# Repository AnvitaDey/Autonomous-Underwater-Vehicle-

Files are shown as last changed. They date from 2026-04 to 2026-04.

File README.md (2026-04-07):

# Autonomous Underwater Vehicle (AUV)

Developed this project as part of the **Robofest Gujarat 5.0 (GUJCOST) AUV Challenge**, focusing on designing and building a fully functional Autonomous Underwater Vehicle for real-world underwater tasks.

The system integrates mechanical design, embedded systems, and computer vision to perform operations such as navigation, inspection, and object interaction.

---

## 🚀 Overview

The AUV features:

* PVC frame for structural strength and low drag
* Six-thruster configuration enabling multi-axis control
* Raspberry Pi for high-level processing and Pixhawk (ArduSub) for stabilization
* Vision pipeline using OpenCV for perception tasks

The vehicle is capable of controlled motion in surge, sway, heave, and yaw, ensuring stable underwater navigation.

---

## ⚙️ System Design

### Mechanical System

* Rigid and modular frame design with balanced mass distribution
* 6 thruster configuration for dof 
* Waterproof electronics enclosure
* Dedicated mounts for sensors, camera, and manipulator

### Electronics & Control

* Pixhawk 2.4.8 for real time control and sensor fusion
* Raspberry Pi 4 running BlueOS and ROS2
* ESC-controlled BLDC motors for propulsion
* Sensors: camera, pressure sensor, leak detection

### Software

* ROS2 + MAVROS architecture
* MAVLink communication
* OpenCV-based perception
* QGroundControl for monitoring and mission execution
* 
---

## Contributions

* Designed key mechanical components and assemblies using **Fusion 360**
* Worked on structural layout, stability, and component integration
* Developed mounts and enclosure systems for underwater operation
* Contributed to vision pipeline with **HSV-based color segmentation using OpenCV**

---

## 🏆 Achievements

* Advanced to **Round 2** in Robofest Gujarat 5.0
* Secured **₹50,000 in project funding**
* Successfully developed and presented a working prototype

---

## 📂 Repository Structure

* `mechanical-design/` → CAD models and components
* `system-design/` → full AUV assemblies and iterations
* `gripper/` → manipulator design
* `system architecture/` → circuit diagram 

---

## 📄 Technical Documentation

For a detailed breakdown of system design, hardware architecture, and implementation:

[View Full Technical Report](./Technical_Document_Final.pdf)

## 🛠️ Tools & Technologies









---

## 📸 Preview

AUVbody_ideation

---

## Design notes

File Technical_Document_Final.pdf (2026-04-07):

Gujarat Council on Science & Technology Dept. of Science & Technology, Govt. of Gujarat

Technical Report for
Level-2 Proof of Concept (PoC) Stage for
ROBOFEST-GUJARAT 5.0 Competition Level: Senior
Category: Autonomous Underwater Vehicle
Application No.: R520251182
Name of Mentor: Pramod Sreedharan
Name of Institute: Amrita Viswa Vidyapeetham, Amritapuri Campus Mobile No.: 9347682107
E-mail Id: : raviganesh812@gmail.com

### 1. Perspective View of the Robot

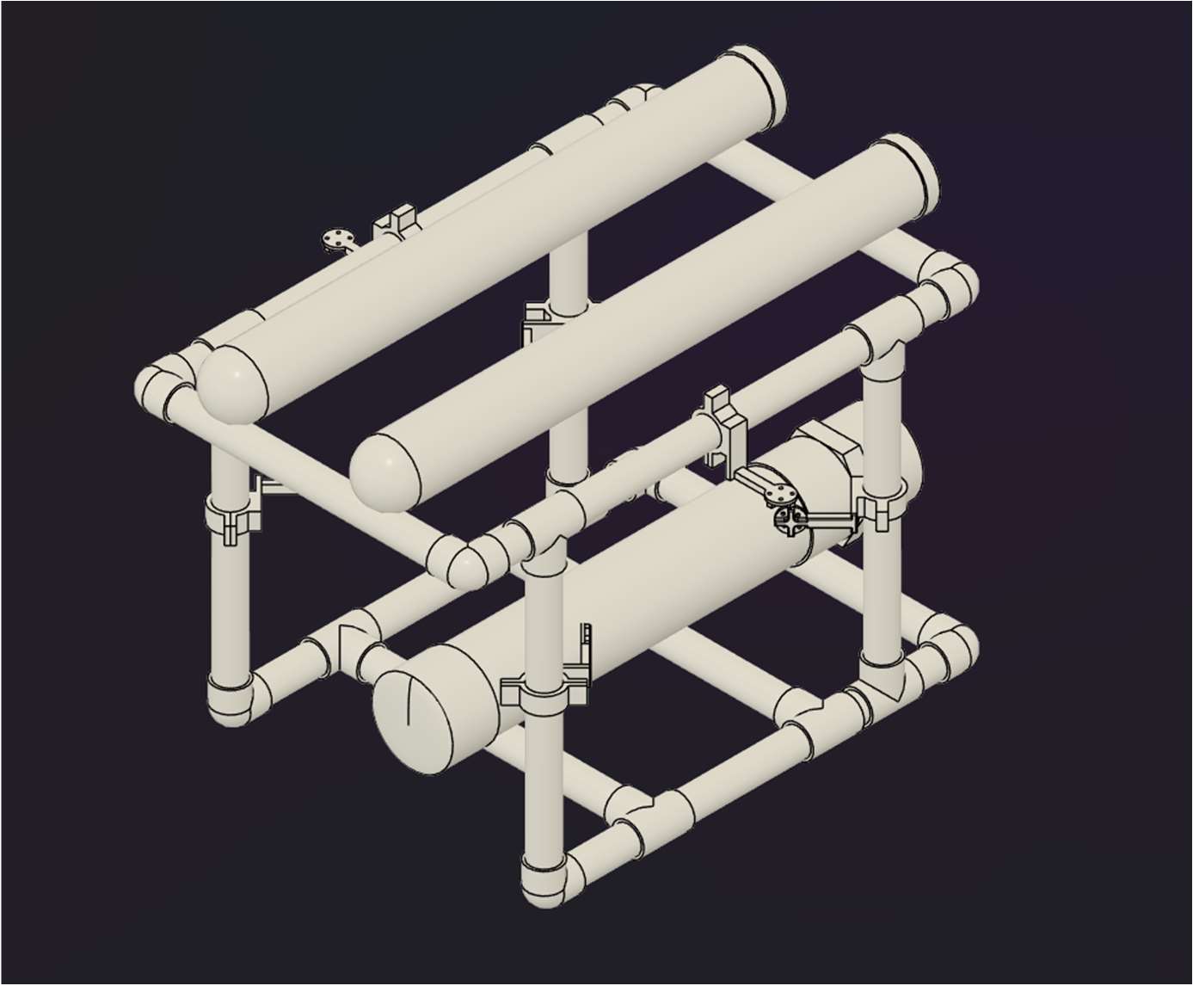
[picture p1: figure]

- Description:
The proposed robot is an Autonomous Underwater Vehicle (AUV) designed for underwater exploration and intervention tasks. It features a hydrostatically stable PVC hull with an acrylic front dome for optical clarity. The vehicle is equipped with six underwater thrusters arranged in a vectored configuration for full motion control in surge, sway, heave, and yaw. Core intelligence is managed by
a Raspberry Pi 5 running ROS 2 Humble, handling sensor fusion, mission planning, and manipulator control. A Pixhawk 2.4.8 flight controller provides low-level thruster control and stabilization. The system integrates multiple sensors including stereo cameras, depth sensors, hydrophones, and leak detectors for comprehensive environmental perception and task execution
a. Design Outlay and Description:

o The Autonomous Underwater Vehicle (AUV) is designed as a compact and modular robotic system capable of stable underwater navigation, depth control, and visual inspection. The overall design integrates a rigid mechanical frame, a six-thruster propulsion configuration, and a balanced mass distribution to ensure stability and maneuverability in a submerged environment. The thrusters are symmetrically arranged using a combination of clockwise and counter-clockwise motors, enabling full control over all degrees of freedom and minimizing unwanted torque effects. The mechanical layout also accommodates a sealed electronics enclosure, battery placement for a low center of gravity, and front-mounted sensors and manipulator for operational tasks.
o The control architecture of the AUV follows a layered design approach, where low-level control and stabilization are handled by a Pixhawk flight controller running ArduSub firmware, while high-level processing and communication are managed by a Raspberry Pi running BlueOS. Sensor inputs such as depth and orientation are continuously processed to generate real-time control outputs for precise motion control. Communication with the ground control station is achieved through Ethernet using QGroundControl, enabling monitoring, configuration, and mission execution. This integrated design ensures reliable operation, scalability, and suitability for both manual and autonomous underwater missions.
b. Description of Hardware:
This section describes the complete hardware architecture of the Autonomous Underwater Vehicle (AUV). The system is designed to provide stable underwater propulsion, precise control, sensing, and onboard computation using commercially available components.
b1. Mechanical System
The AUV is designed with a rigid frame structure with PVC pipes that supports propulsion units, electronics enclosure, battery mounting, and a front-facing manipulator. The frame ensures structural integrity while minimizing hydrodynamic drag during underwater operation.
Frame and Layout
- The propulsion motors are symmetrically mounted around the vehicle’s center of mass to ensure balanced thrust and maneuverability.
- Electronics such as the Pixhawk, Raspberry Pi, power distribution board, and power module are housed inside a sealed waterproof enclosure.
- Batteries are mounted low in the frame to improve stability and maintain a low center of gravity.
- A front-mounted camera provides visual feedback for navigation and manipulation tasks.
- A servo-actuated manipulator is attached at the front of the vehicle for object interaction. b2. Drive System & Controller
Propulsion Motors
The AUV uses a total of six Brushless DC (BLDC) motors for underwater propulsion:
- 3 × CW BLDC Motors (920 KV)
- 3 × CCW BLDC Motors (920 KV)
These motors are arranged in pairs to counteract torque effects and improve directional stability. The use of both clockwise (CW) and counter-clockwise (CCW) motors eliminates unwanted rotational moments during operation.
Key Features: - High efficiency and reliability - Suitable for continuous operation - Capable of providing sufficient thrust for underwater maneuvering.
Electronic Speed Controllers (ESCs)
- 6 × 30A ESCs are used to control the speed and direction of the BLDC motors.
- Each ESC receives PWM control signals from the Pixhawk autopilot.
- ESCs are powered directly from the battery through the power distribution board. Functions of ESCs: - Converts DC battery power into three-phase AC for BLDC motors -Enables precise motor speed control - Supports rapid response to control commands

Flight Controller / Autopilot
- Pixhawk 2.4.8 is used as the primary control unit.
- Runs ArduSub firmware, specifically designed for underwater vehicles.
- Handles real-time control tasks such as:
o Stabilization
o Thruster mixing
o Sensor fusion
o Navigation and depth control
Companion Computer
- Raspberry Pi 4 Model B acts as the companion computer.
- Runs BlueOS, which manages:
o MAVLink communication
o Video streaming
o Network connectivity
o High-level control and extensions
The Raspberry Pi communicates with the Pixhawk via USB/UART using the MAVLink protocol.
Manipulator Control
- A servo motor is used to actuate the manipulator mechanism.
- Controlled directly by the Pixhawk through a PWM output.
- Enables grasping or interaction with underwater objects.
b3. Electronics & Instrumentation: Power System
a) Battery
- 2 × 14.8V (4S) 5200 mAh LiPo batteries are used.
- High discharge rating (40C–80C) ensures sufficient current for motors and electronics.
b) Power Distribution Board (PDB)
- Distributes battery power to:
o ESCs
o Power module
- Ensures organized and safe power routing.
c) Power Module
- Steps down battery voltage and supplies regulated power to the Pixhawk.
- Provides voltage and current sensing for real-time monitoring.
d) Computing and Control Electronics
Component | Function
Raspberry Pi 4 | Companion computer, BlueOS, video processing
Pixhawk 2.4.8 | Autopilot, motor control, sensor fusion
ESCs | Motor control
PDB | Power distribution

Sensors
a) Camera
- Raspberry Pi camera module is used for real-time underwater vision.
- Mounted at the front of the vehicle.
- Used for navigation, inspection, and object detection.
b) Pressure Sensor
- MS5837-02BA waterproof pressure sensor is used.
- Provides accurate depth measurement.
- Communicates with the Pixhawk via I2C.
- Functions: - Depth estimation - Altitude hold - Safety monitoring b4. Working Level Software

Raspberry Pi – mission computer

- OS: BlueOS
- Framework: ROS2 – MAVRos, using python and C
- Communication protocols: MAVLink
- Vision system: OpenCV
- Qground control, Mission planner

Pixhawk 2.4.8 - Flight Controller

- Firmware – ArduSub
1. Complete and exhaustive listing of all the hardware / component / equipment (electronics and mechanical)
A. Controller of the Robot:

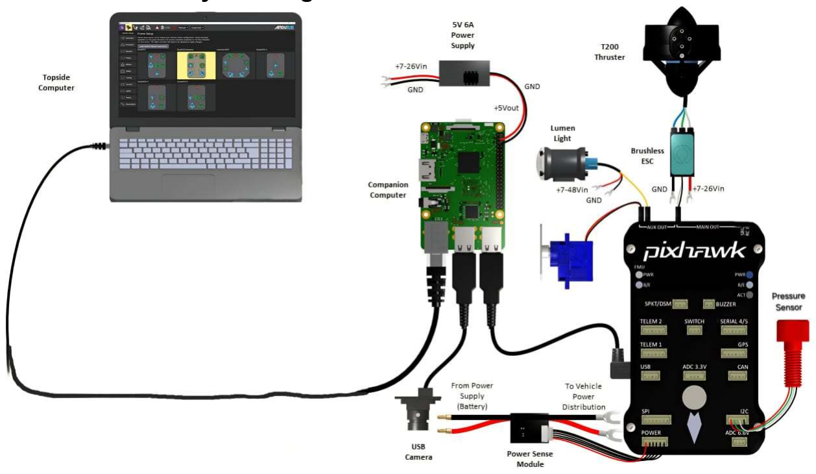
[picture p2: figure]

Electrical assembly & wiring

Power Connections

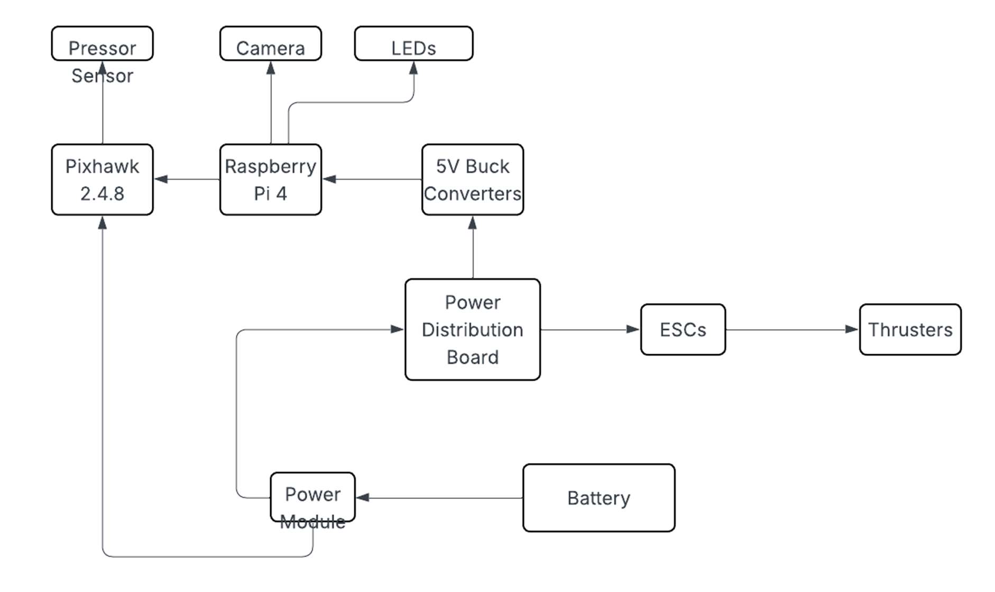
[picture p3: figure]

List Of Components:

Sln. | Component | Model / Specification | Quantity | Description
1 | Brushless DC Motor (CCW) | Pro Range DX2312, 960 KV (CCW) | 3 Provides thrust for | propulsion and maneuvering in counter-clockwise direction; used for balanced thrust in AUV
2 | Brushless DC Motor (CW) | Pro Range DX2312, 960 KV (CW) | 3 Clockwise rotating | motors paired with CCW motors to eliminate torque imbalance
3 Electronic Speed Controller | (ESC) | Simplifly ESC, 30A | 6 | Controls speed and direction of BLDC motors based on PWM signals from Pixhawk
4 | Servo Motor | Standard RC Servo Motor | 1 Used for | manipulator actuation to grip or interact with underwater objects
5 | Lithium Polymer Battery | GenX Power 11.1V (3S), 5200mAh, 40C | 2 Primary power | source supplying high current for motors and onboard electronics

6 | Power Module | Pixhawk Power Module (Voltage & Current Sensor) | 1 Regulates power to | Pixhawk and monitors battery voltage/current
7 | Power Distribution Board (PDB) | Drone Power Distribution Board | 1 Distributes battery | power evenly to all ESCs and onboard electronics
8 | Flight Controller | Pixhawk 2.4.8 | 1 | Main autopilot unit responsible for stabilization, navigation, and control
9 | Companion Computer | Raspberry Pi 4 Model B - 8gb ram | 1 Runs BlueOS, | handles vision processing, networking, and high-level control
10 | Camera Module | Raspberry Pi Camera Module | 1 Provides live video | feed for navigation, monitoring, and inspection
11 | Pressure Sensor | MS5837-2BA Waterproof Pressure Sensor | 1 Measures water | pressure to calculate depth of the AUV
12 | Ethernet Cable | CAT6 Ethernet Cable | 1 | Used for communication between Raspberry Pi and surface control station
B. Mechanical Components
a. Mechanical Modules
The AUV features a rigid, lightweight frame designed to support propulsion units, electronics, batteries, sensors, and a manipulator. Six thrusters are symmetrically mounted to enable full 6-degree-of-freedom motion. Dedicated mounts are provided for the Pixhawk, Raspberry Pi, camera, and pressure sensor, ensuring stability and easy maintenance.
b. Fabrication Components
The frame and mounts are fabricated using aluminum, PVC, and 3D-printed components for strength and corrosion resistance. Waterproof enclosures protect electronic components, while stainless-steel fasteners and brackets ensure secure assembly in underwater conditions.
c. Tools and Equipment Used
Basic fabrication tools such as drills, screwdrivers, soldering iron, multimeter, and 3D printer are used for assembly, wiring, and waterproof sealing.
C. Motor System Used & Assembly

The AUV uses six D2212 920KV BLDC motors (three CW and three CCW) controlled by 30A ESCs. This balanced configuration minimizes torque effects and improves stability. Motors are securely mounted to the frame, with ESCs connected to a power distribution board and controlled via PWM signals from the Pixhawk, enabling precise thrust and manoeuvring control.

### 2. Complete and exhaustive listing of all the software used in Robo-making

A.Software Used

A1. BlueOS
Why BlueOS for an AUV
- Advantages over standard Raspberry Pi OS
- Pre-configured MAVLink routing
- Built-in ArduSub support
- Web-based UI (no monitor needed)
- Integrated video streaming
- Designed specifically for ROV/AUV use Hardware Requirements
- Mandatory
- Raspberry Pi 4 Model B (8GB)
- Pixhawk (Pixhawk 2.4.8)
- SD card
- Ethernet cable
- Stable 5V 3A power supply for Pi
- Additional
- USB camera / CSI camera
- Depth sensor (I2C)
- Leak sensor
Companion sensors
- Power System Design
Battery (3S / 4S Li-ion or LiPo)
|→ Buck Converter (5V 3–5A)
| | → Raspberry Pi 4
|→ Power Module
| → Pixhawk
Flashing ArduSub
BlueOS → Autopilot Firmware - Select ArduSub - Select Pixhawk model – Flash firmware Pixhawk Connection
- Pixhawk USB → Pi USB
MAVLink in BlueOS
- MAVLink Flow
Pixhawk ⇄ BlueOS ⇄ Laptop (QGC)

A2. QGroundControl:

QGroundControl (QGC) is the primary Ground Control Station (GCS) software used for monitoring, controlling, and configuring the Autonomous Underwater Vehicle (AUV). In this system, QGroundControl interfaces with the Pixhawk autopilot running ArduSub firmware through the Raspberry Pi companion computer running BlueOS. It provides a unified graphical interface for vehicle setup, real-time telemetry visualization, mission planning, and manual control.

Role of QGroundControl in the AUV System

In the proposed AUV architecture, QGroundControl functions as the operator-facing control and monitoring platform. It does not directly control motors or sensors but communicates with the Pixhawk via MAVLink messages routed through BlueOS. QGC enables the operator to supervise vehicle behavior, issue commands, and visualize system health in real time.

Connection and Initialization Process
1. The Raspberry Pi and Pixhawk are powered ON.
2. BlueOS boots and establishes MAVLink communication with the Pixhawk.
3. The laptop is connected to the Raspberry Pi using an Ethernet cable.
4. QGroundControl is launched on the laptop.
5. QGC automatically connects to the AUV and displays vehicle status.
No manual port configuration is required, as BlueOS manages MAVLink routing.

The communication chain is established as follows:
QGroundControl (Laptop)
⇅ MAVLink (UDP)
Raspberry Pi 4 (BlueOS)
⇅ MAVLink (USB/UART)
Pixhawk 2.4.8 (ArduSub)

Operational Control Modes
QGroundControl allows the operator to select and monitor different control modes supported by ArduSub:
- Manual Mode: Direct operator control of thrusters
- Stabilized Mode: Automatic attitude stabilization
- Depth Hold Mode: Maintains constant depth using pressure sensor feedback
- Autonomous / Assisted Modes: Executes predefined behaviors or missions Mode changes are transmitted as MAVLink commands.

Real-Time Monitoring and Telemetry
QGroundControl displays real-time telemetry data, including:
- Vehicle attitude (roll, pitch, yaw)
- Depth and vertical velocity
- Battery voltage and current
- Thruster output levels
- Sensor health and system status
Graphical indicators and warnings assist the operator in maintaining safe operation.

Mission Planning and Control
For semi-autonomous operation, QGroundControl enables:
- Creation of waypoint-based missions
- Depth and speed constraints

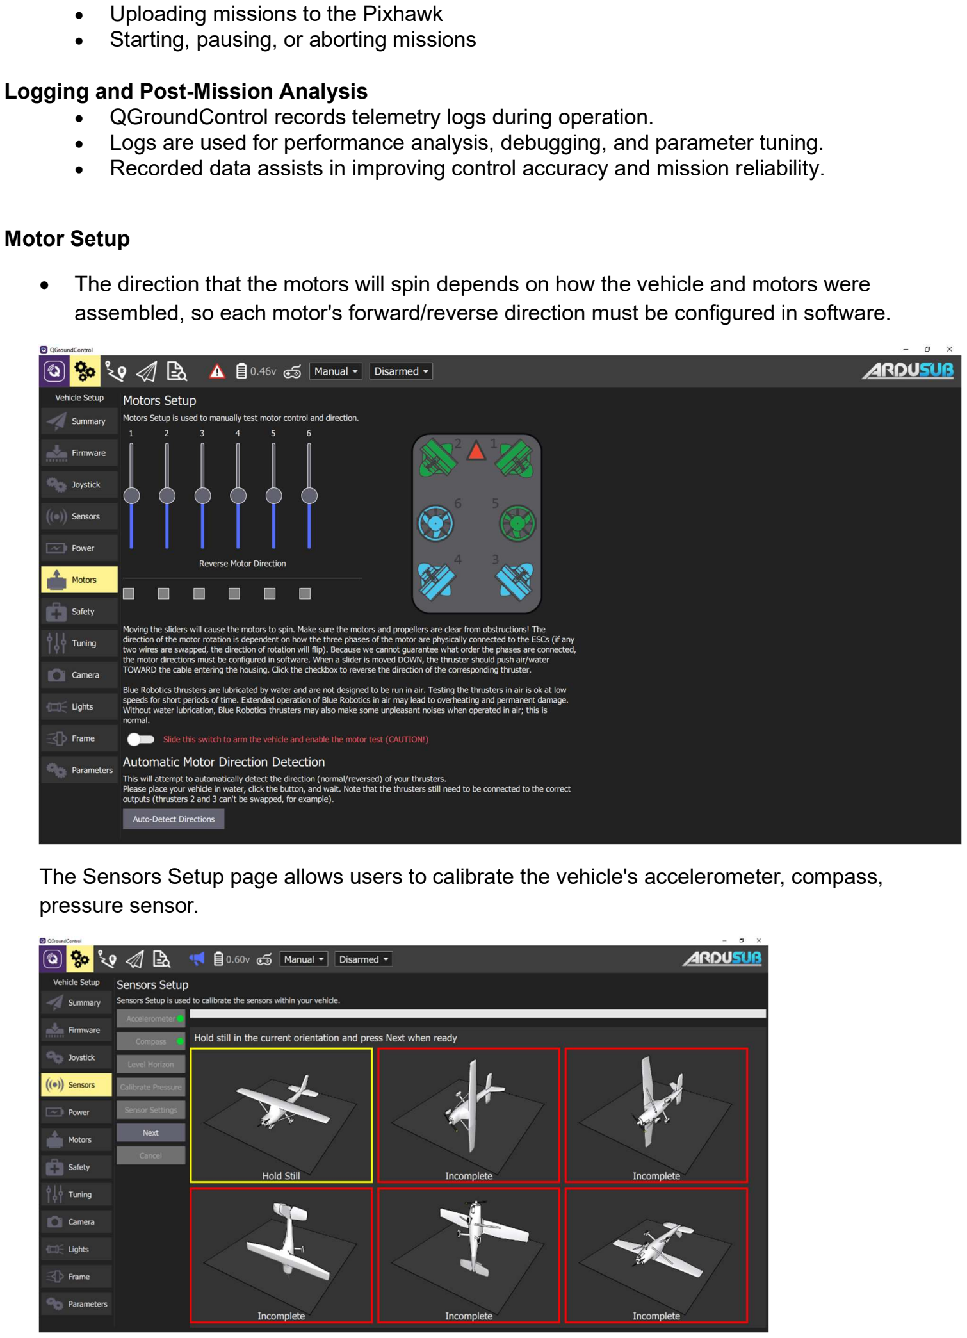
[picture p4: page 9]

- Uploading missions to the Pixhawk
- Starting, pausing, or aborting missions

Logging and Post-Mission Analysis
- QGroundControl records telemetry logs during operation.
- Logs are used for performance analysis, debugging, and parameter tuning.
- Recorded data assists in improving control accuracy and mission reliability.

Motor Setup

- The direction that the motors will spin depends on how the vehicle and motors were assembled, so each motor's forward/reverse direction must be configured in software.

The Sensors Setup page allows users to calibrate the vehicle's accelerometer, compass, pressure sensor.

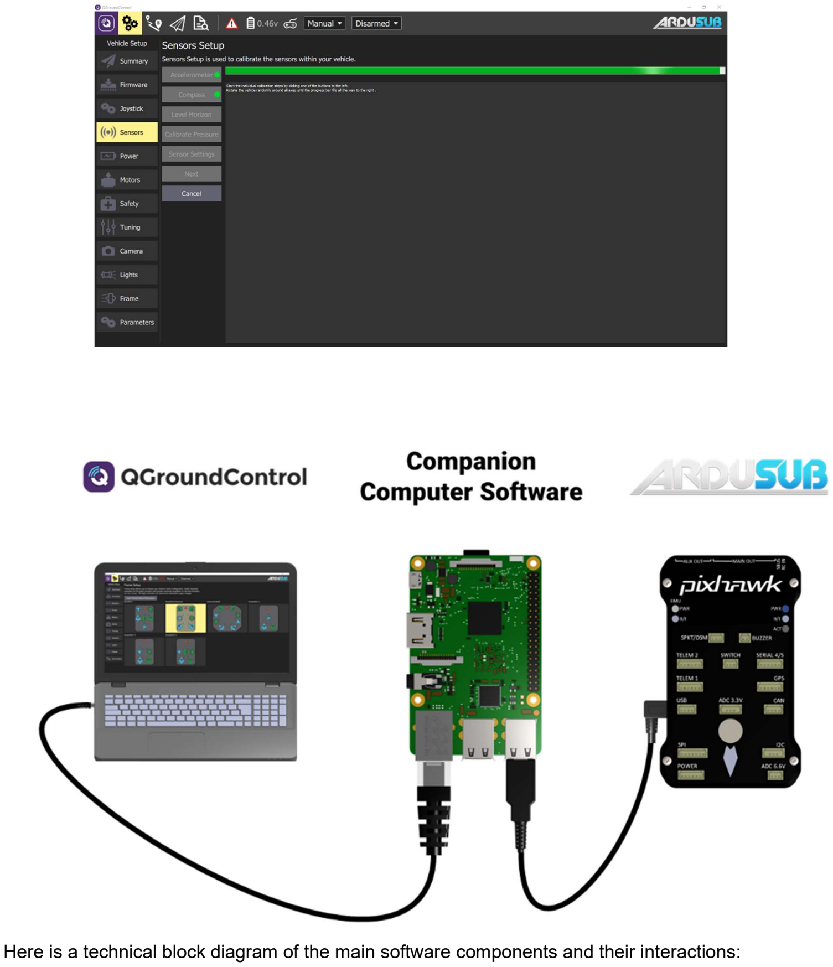
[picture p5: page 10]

Here is a technical block diagram of the main software components and their interactions:

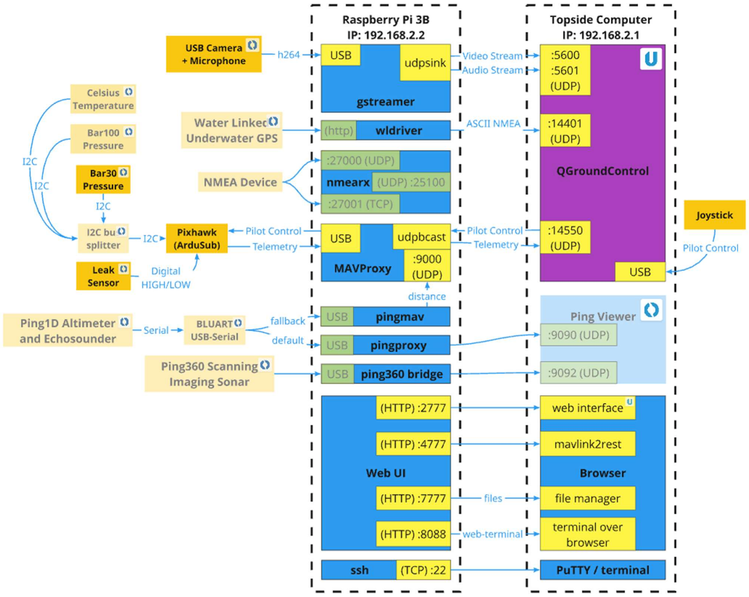
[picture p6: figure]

A3. Pymavlink
ArduSub communicates with a protocol called MAVLink. Pymavlink is a python implementation of the MAVLink protocol. With pymavlink, it is possible to create a python script to read sensor data and send commands to an ArduSub vehicle.

A4. OpenCV
OpenCV (Open Source Computer Vision) is a library to help the development of computer vision software. To perform any real-time image processing with the companion camera, we highly suggest OpenCV to do the job.

Methodology for Software

The main Flow chart of our mission is the basic outline of our whole project. Here, Vehicle Controller is our Pixhawk module which controls the thruster System and the mission computer which controls the Manipulator and receives signals from the sensors and sends signals to Manipulator and controller.

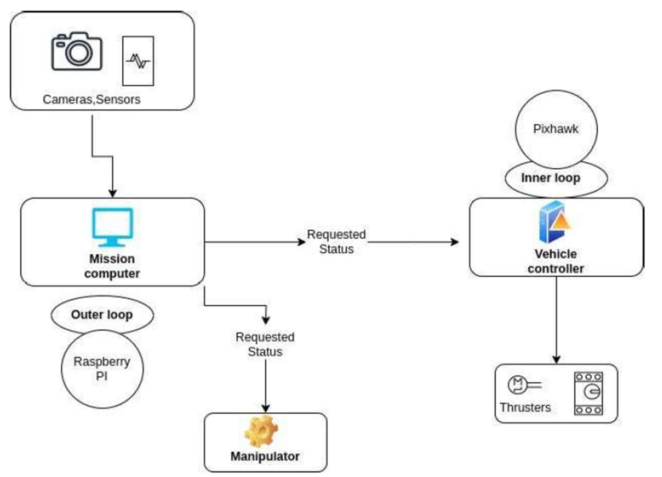
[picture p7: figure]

Now Diving deep into the Inner Loop, this is a Feed Back loop because PID control which stabilizes the system more. But there is a part which we want to focus on, there will be the noise with the data we are receiving from the Accelerometers and Gyroscopes.
Methodology of Automation
Every Autonomous robot has a process,
sensors perception decision control.
Here is the flowchart of Autonomy of our robot in which, Green nodes => Perception
Orange nodes => Decision
Light Green nodes => Control
Red nodes => Fail Safe
For each node, red boxes are the Topics that node Publishing and Blue boxes are the Topics that node subscribed for.

Here, we have two options, we can either Publisher and Subscriber relation or Server and Client relation. We opted for the Publisher and Subscriber Node because we need a continuous supply of data between the sensor and the complementary computer and controller. These continuous supply of data is called Topics. Even though, we have goal.
Now as we can see from the flow chart that our robot will get Perception like gate position, bucket position etc. from Left-hand Side nodes with the help of cameras, Sensors like Depth sensor, Leak sensor, IMU and Hydrophones, then take Decision using the mission_manager_node and Control the Actuator, Manipulator using the AUV_controller_Node, Manipulator_Controller_node also with the failsafe mechanism using the Fail-safe which can Abort the mission and ensures the Robot Safety.

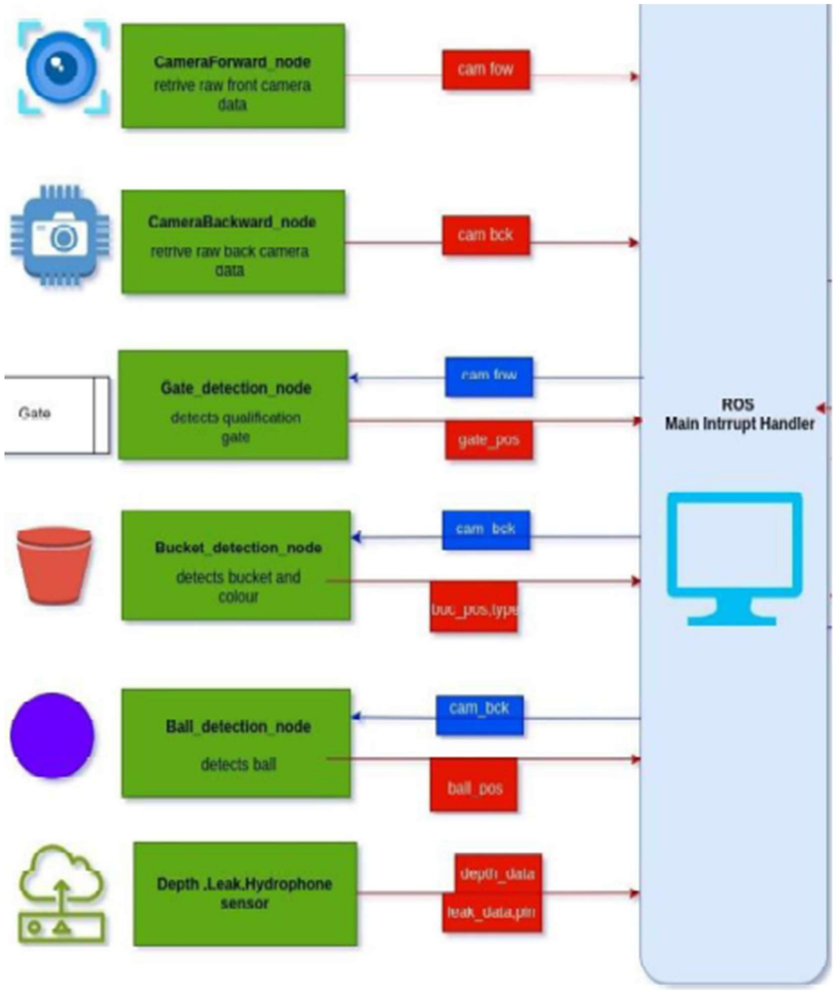
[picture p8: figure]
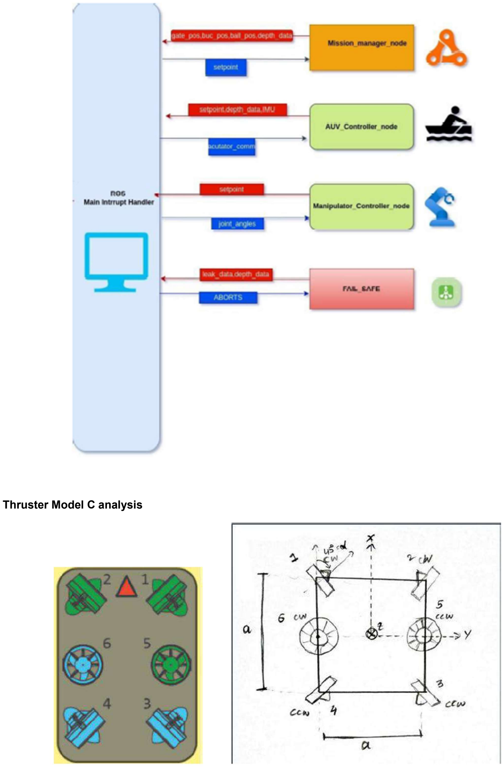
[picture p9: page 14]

Thruster Model C analysis

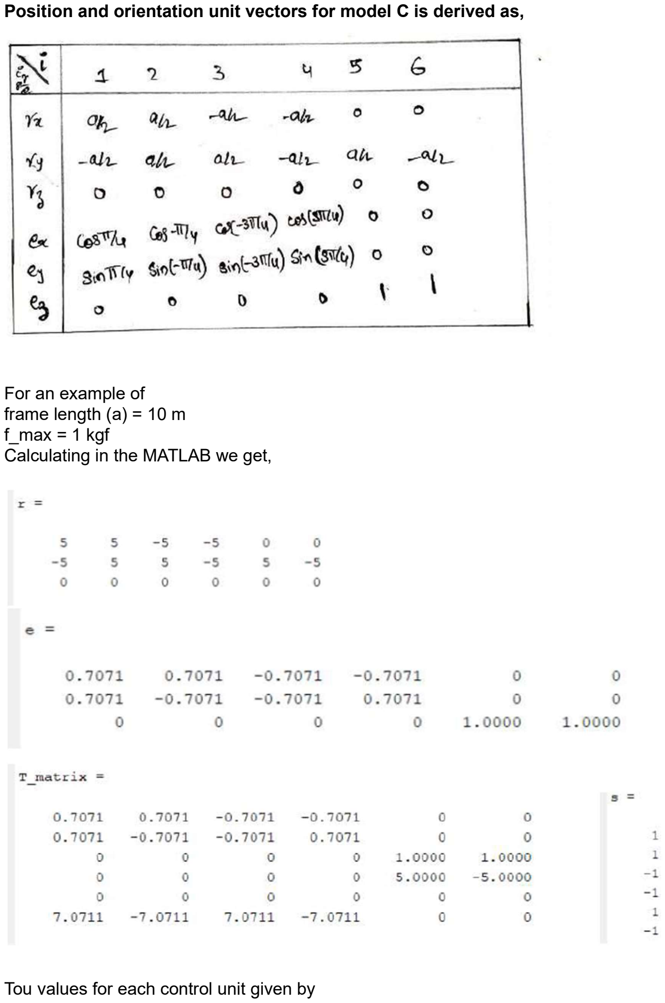
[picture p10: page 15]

Position and orientation unit vectors for model C is derived as,

For an example of
frame length (a) = 10 m
f_max = 1 kgf
Calculating in the MATLAB we get,

Tou values for each control unit given by

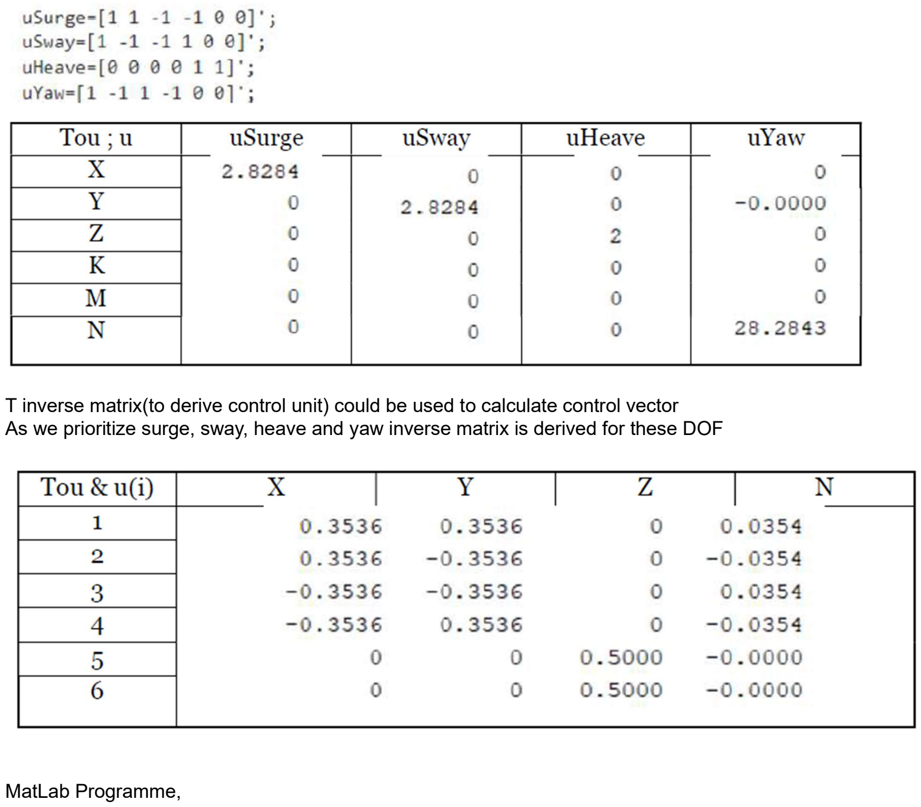
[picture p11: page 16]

T inverse matrix(to derive control unit) could be used to calculate control vector
As we prioritize surge, sway, heave and yaw inverse matrix is derived for these DOF

MatLab Programme,

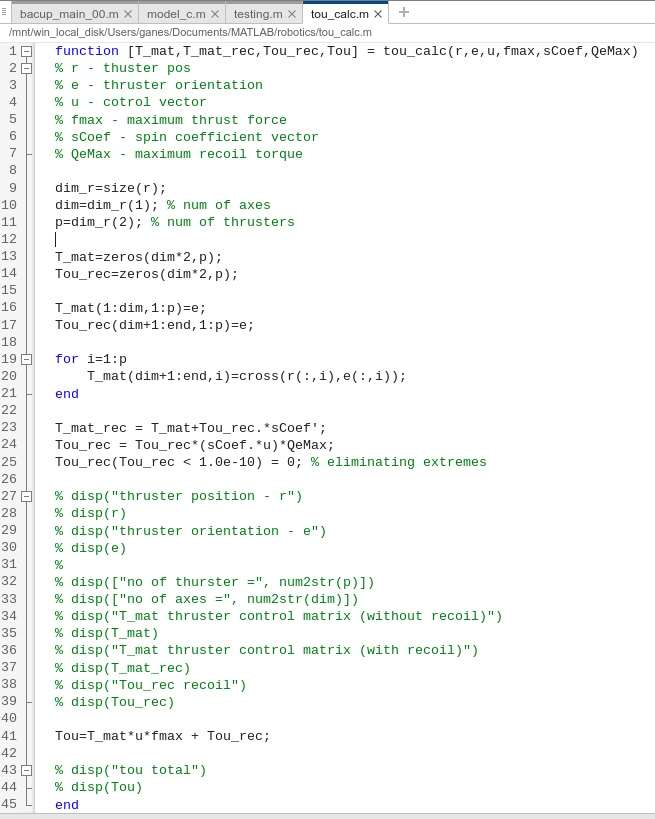
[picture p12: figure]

Propeller Design

OpenProp:
OpenProp is the ideal tool for AUV propeller design because it allows you to move beyond inefficient, off-the-shelf parts to create highly optimized, custom propulsion. By using validated naval theory, it enables you to maximize battery endurance through precise efficiency tuning, account for the unique water flow (wake) created by your AUV’s hull, and perfectly match the propeller to your motor's specific RPM. Ultimately, it provides a fast, cost-free way to go from mathematical optimization to a 3D-printable model, ensuring your vehicle achieves the longest possible mission range.

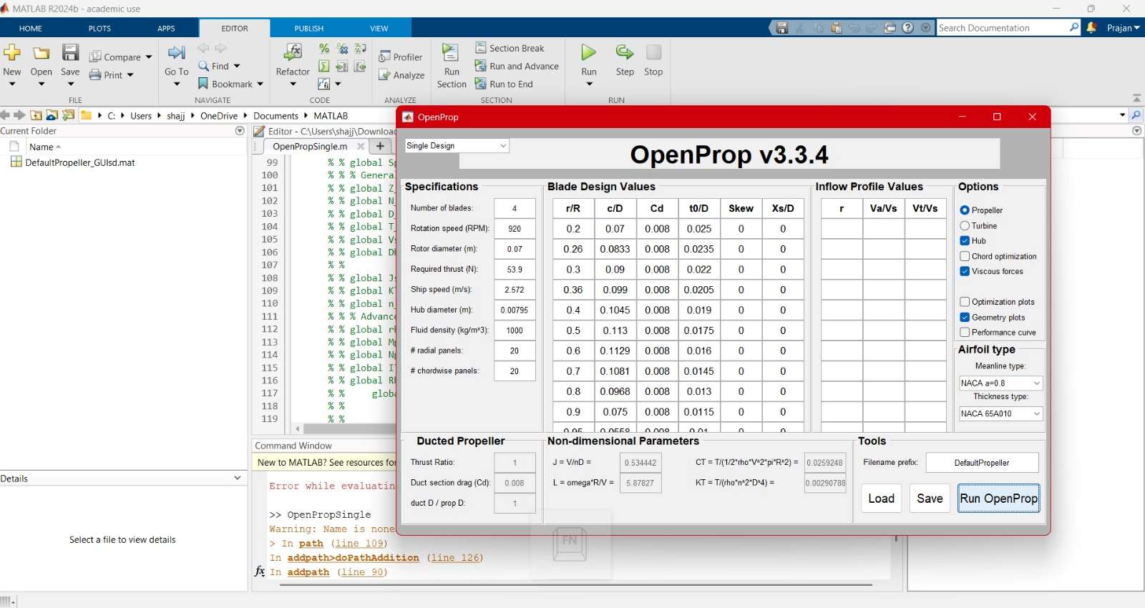
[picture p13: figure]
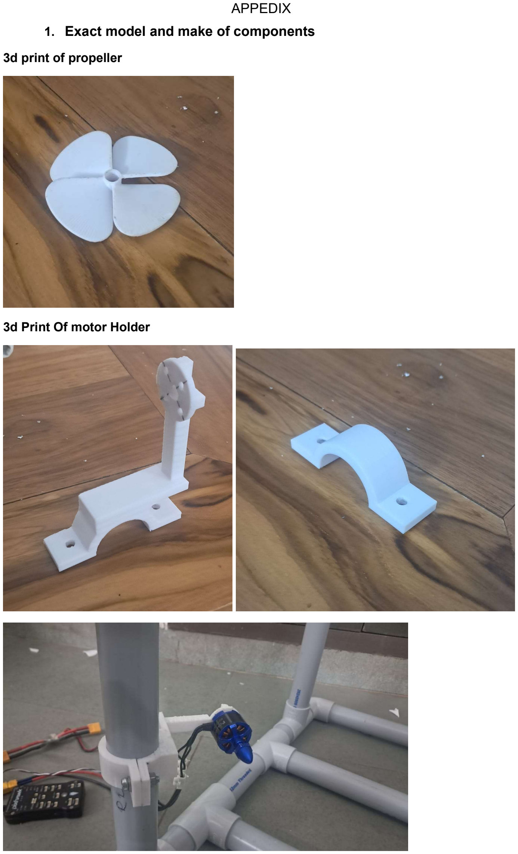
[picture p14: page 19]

APPEDIX

### 1. Exact model and make of components

3d print of propeller

3d Print Of motor Holder

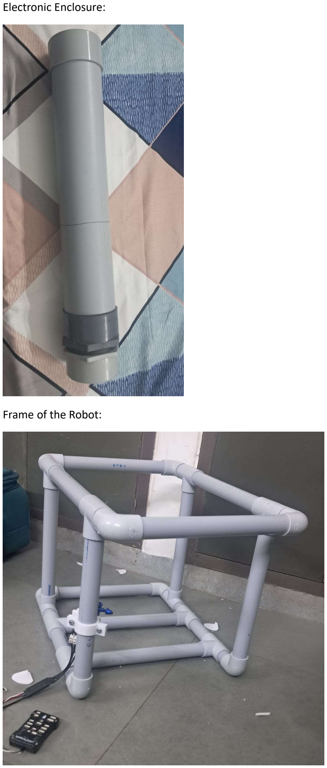
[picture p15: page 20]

Electronic Enclosure:

Frame of the Robot:

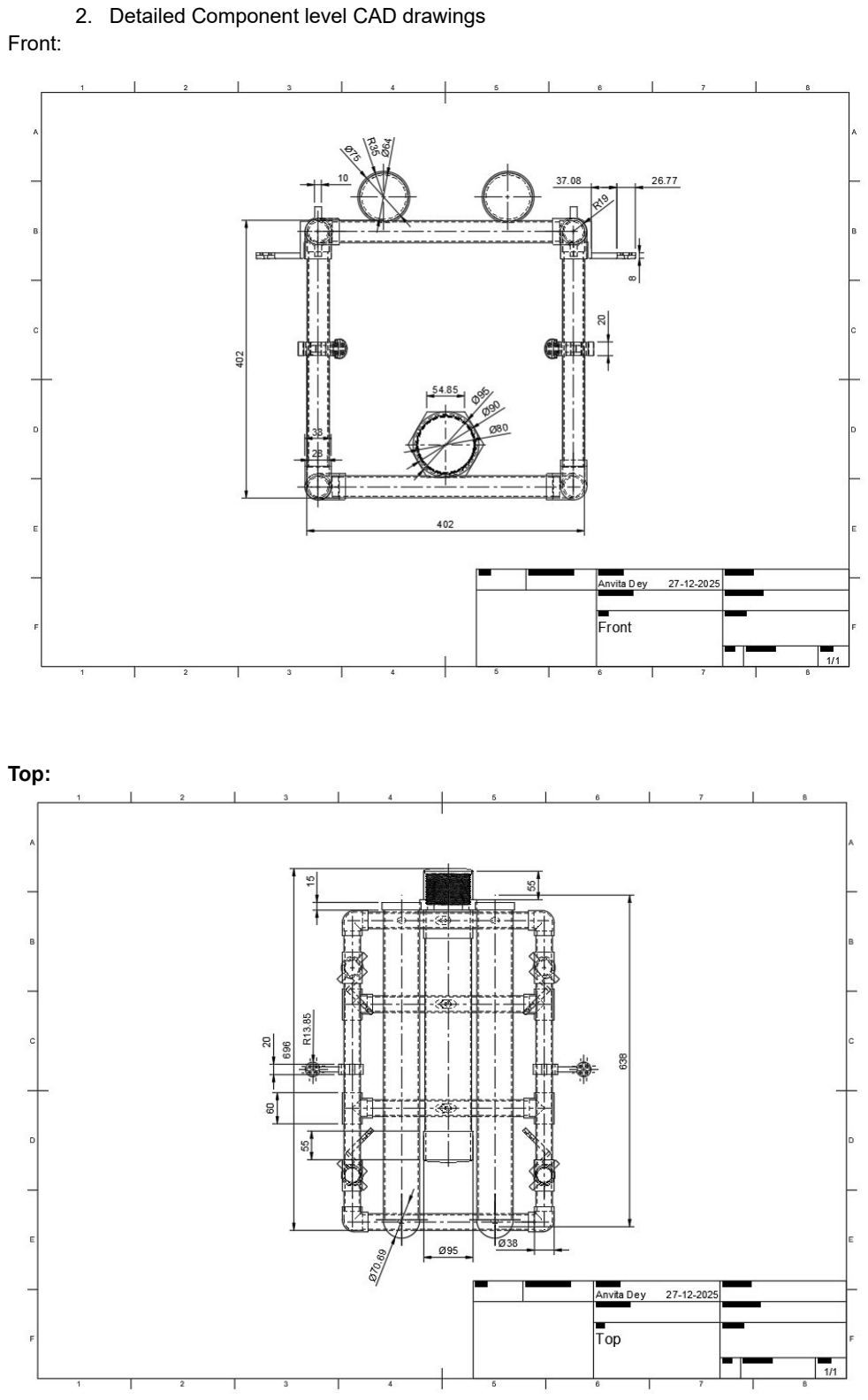
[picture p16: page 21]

### 2. Detailed Component level CAD drawings

Front:

Top:

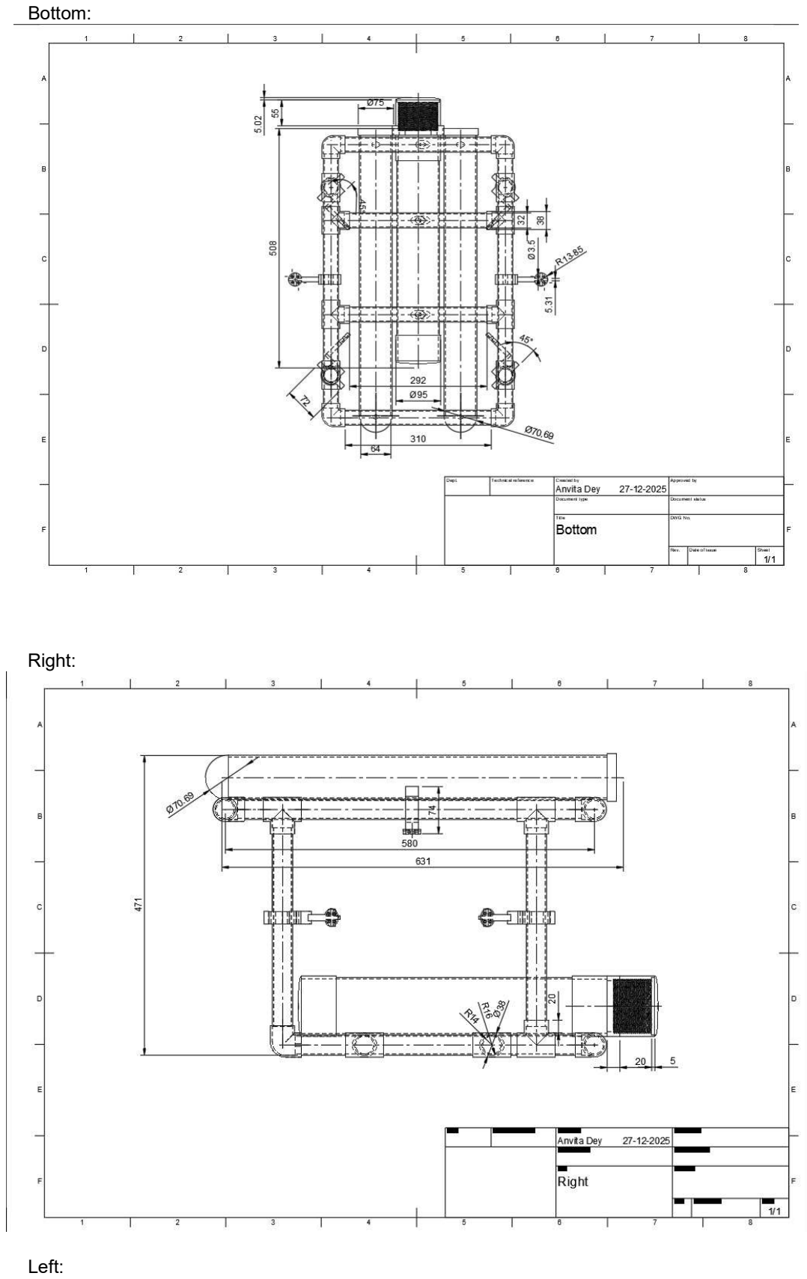
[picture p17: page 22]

Bottom:

Right:

Left:

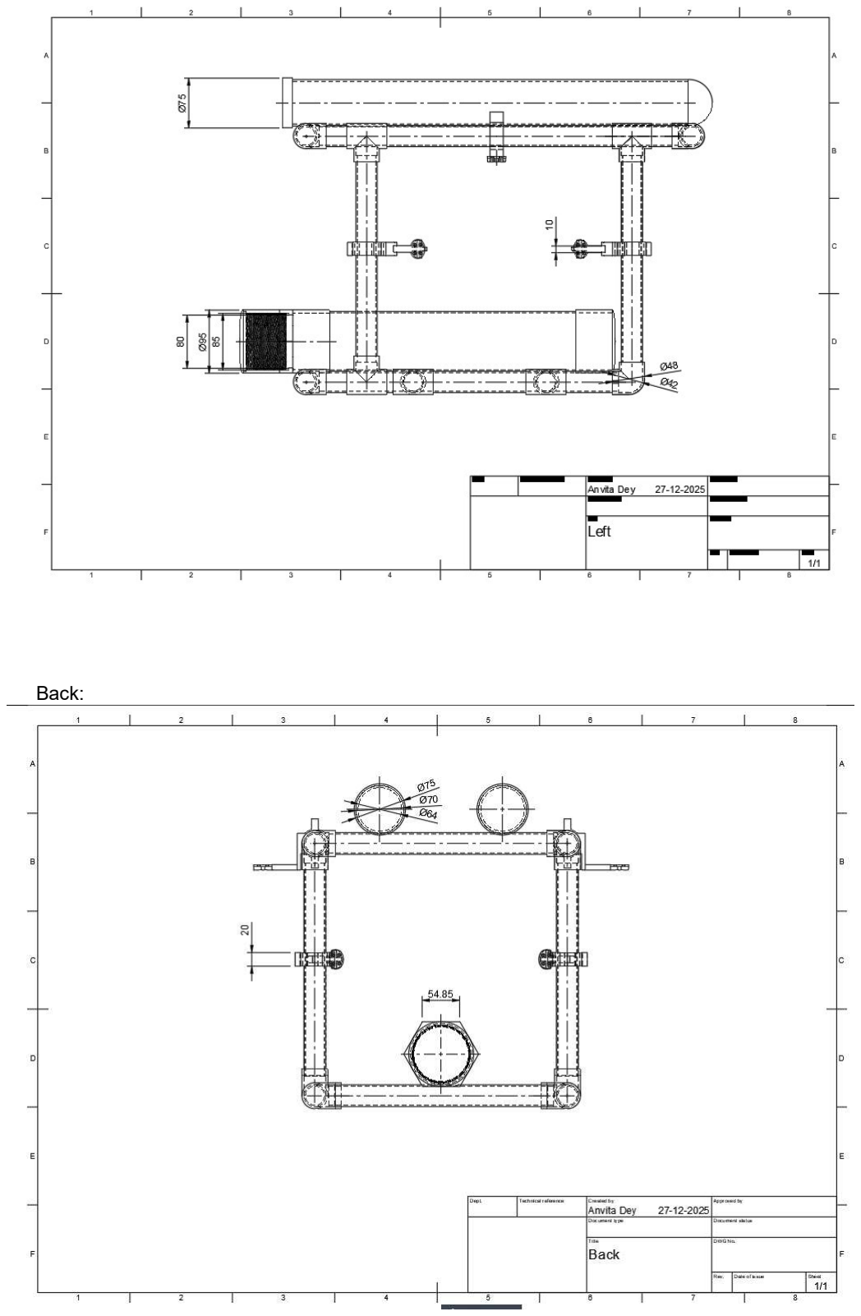
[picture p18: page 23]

Back:

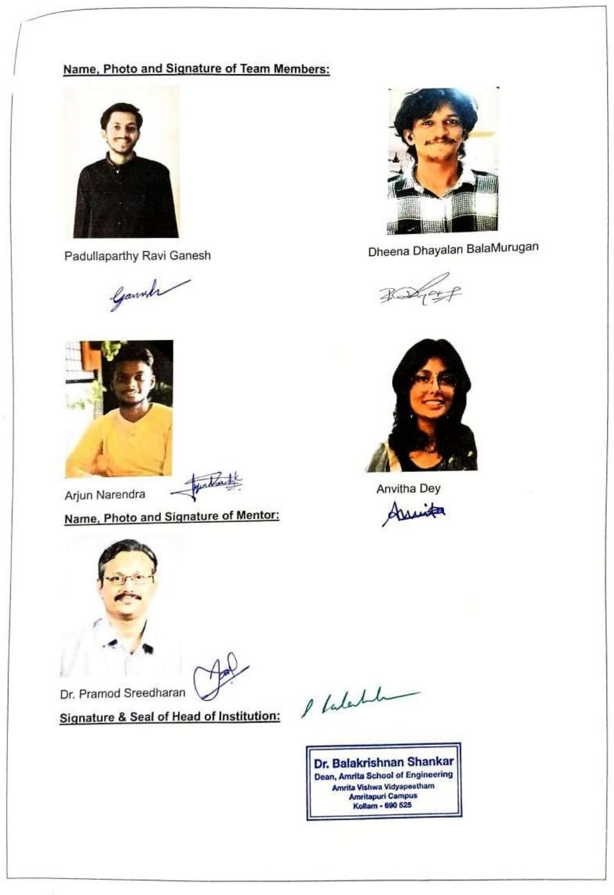
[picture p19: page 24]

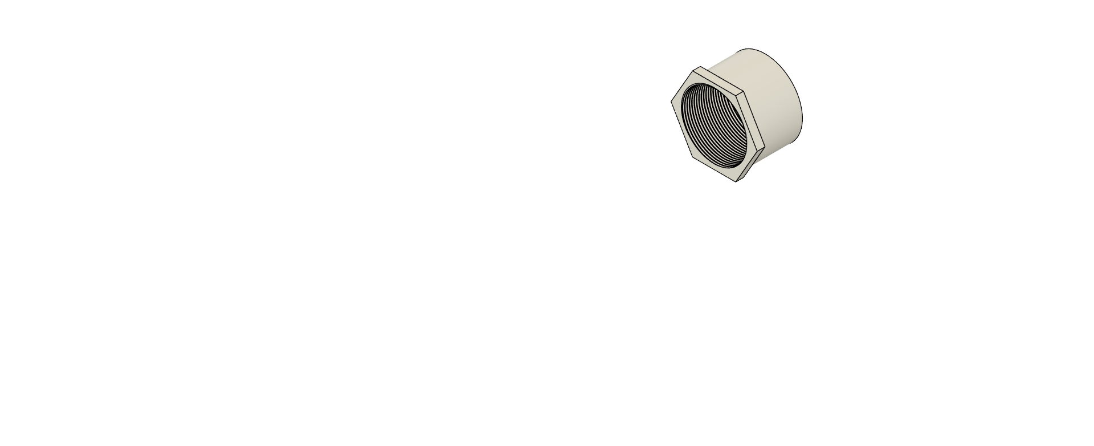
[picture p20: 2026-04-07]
mechanical-design/electronics pipe/elctronics pipe threaded cap .png

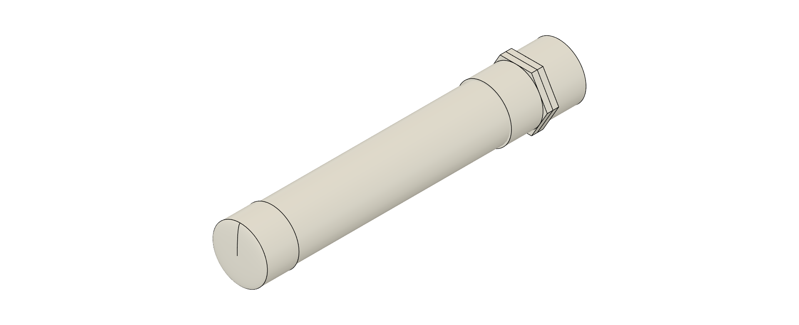
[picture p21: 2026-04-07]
mechanical-design/electronics pipe/elctronics pipe.png

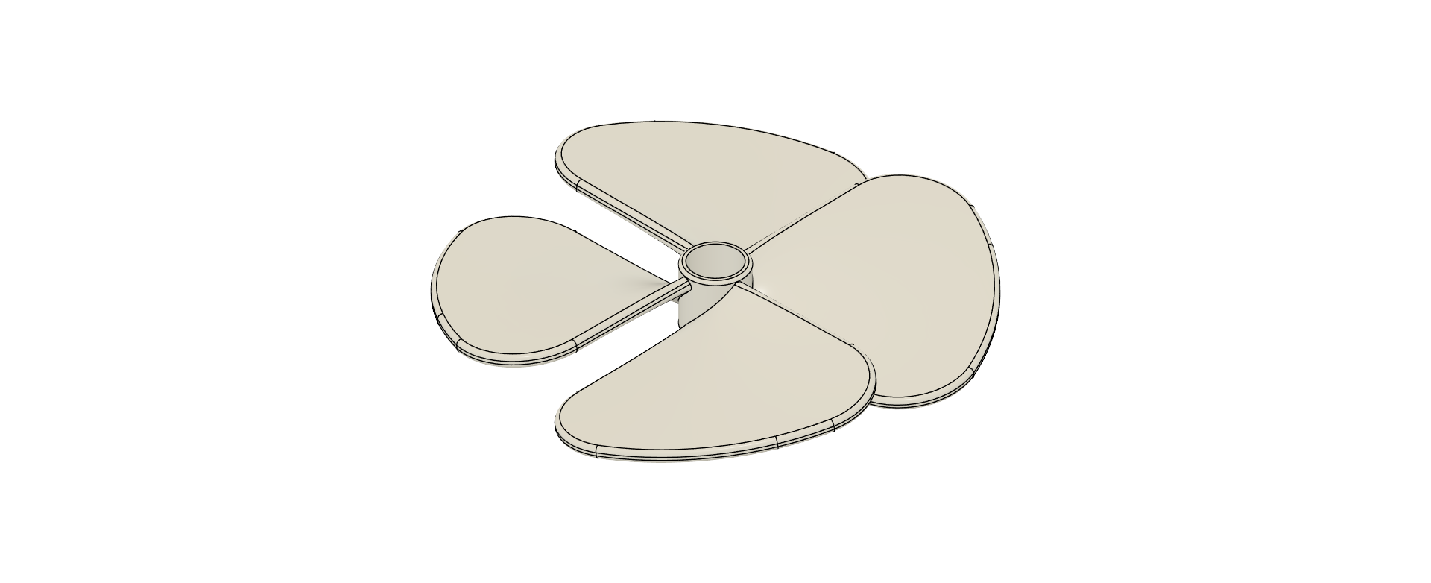
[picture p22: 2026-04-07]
mechanical-design/propeller/Propeller render.png

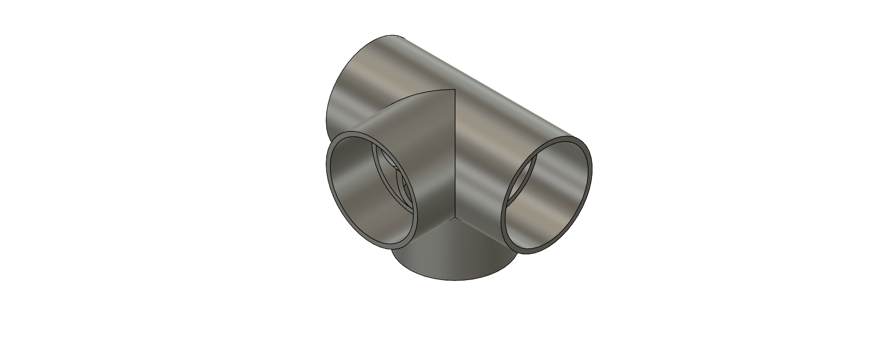
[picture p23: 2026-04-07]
mechanical-design/pvc connectors/4wayteejoint .png

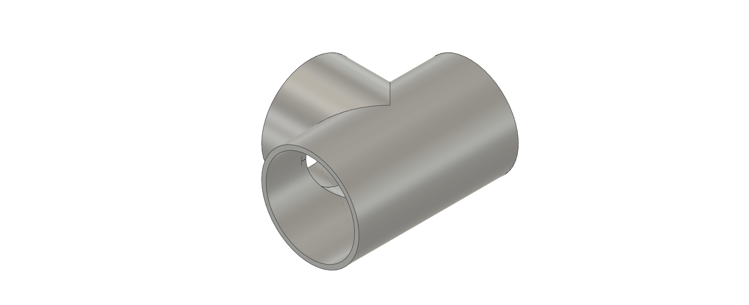
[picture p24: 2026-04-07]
mechanical-design/pvc connectors/Tjoint.png

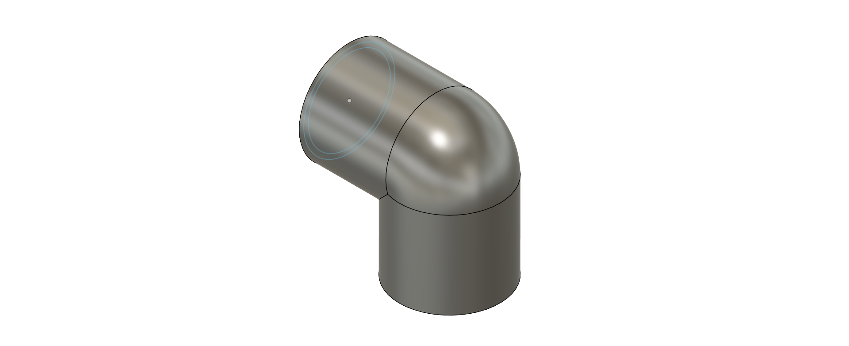
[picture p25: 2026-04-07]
mechanical-design/pvc connectors/elbow.png

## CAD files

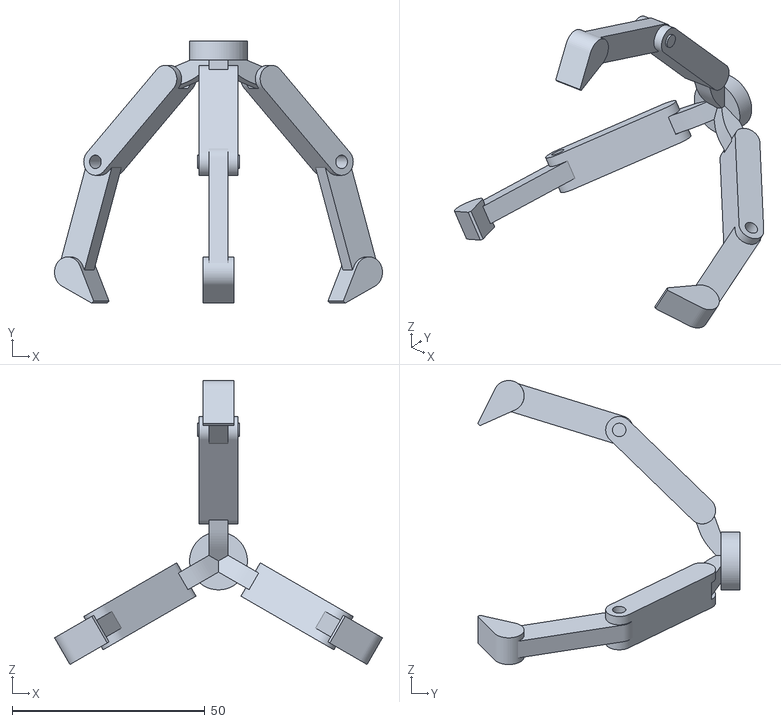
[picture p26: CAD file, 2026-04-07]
gripper/2dof_claw_.stl
85.1 x 68.1 x 73.7

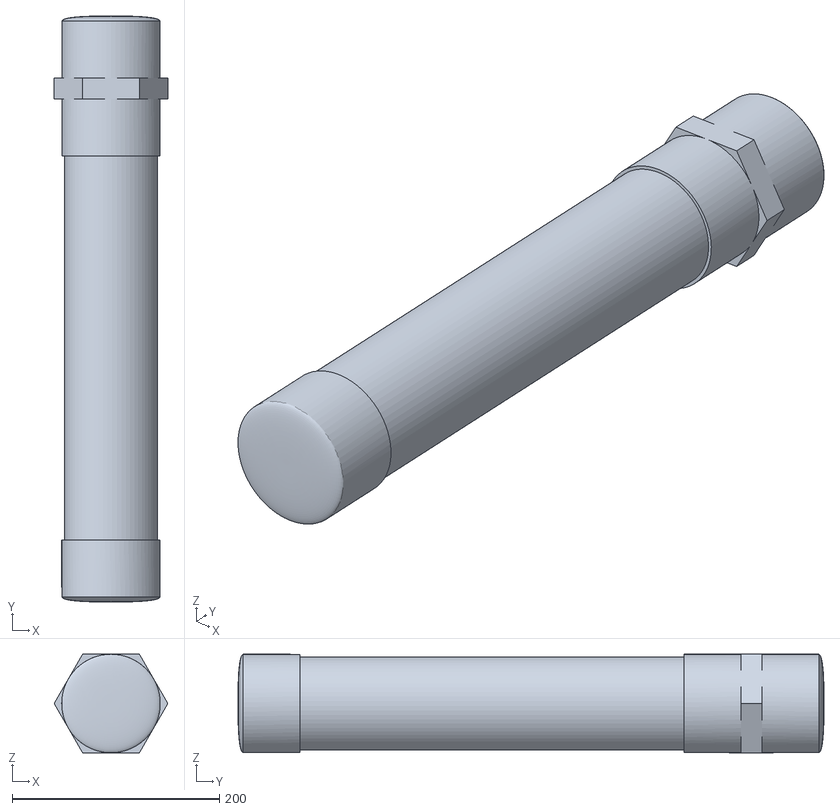
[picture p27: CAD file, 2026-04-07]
mechanical-design/electronics pipe/elctronics pipe.stl
109.7 x 565.0 x 95.0

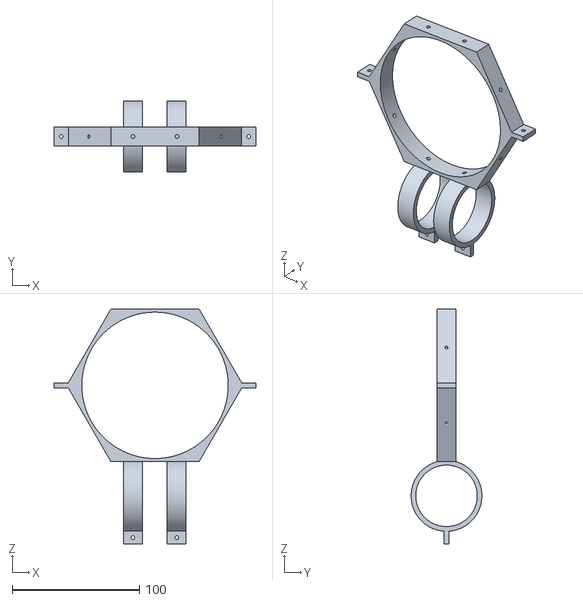
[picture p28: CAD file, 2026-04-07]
mechanical-design/hexa-holder/hexa-holder.stl
158.6 x 55.7 x 184.7

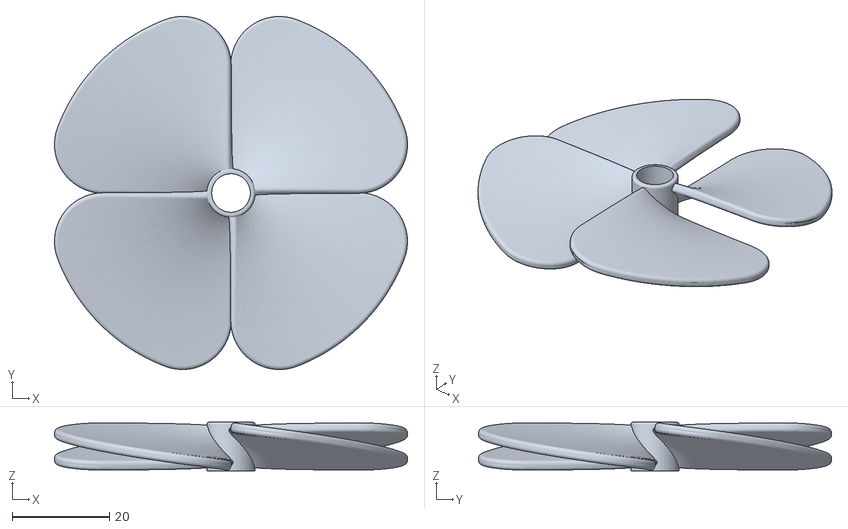
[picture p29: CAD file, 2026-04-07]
mechanical-design/propeller/Propeller_anti-clk.stl
72.5 x 72.5 x 10.0

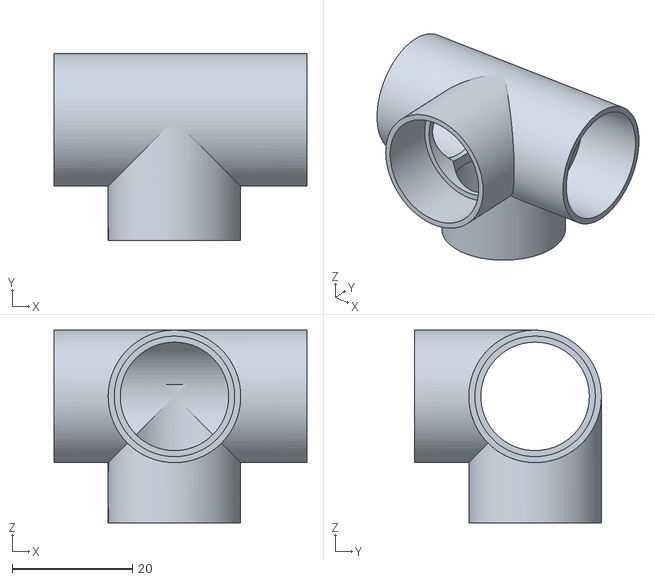
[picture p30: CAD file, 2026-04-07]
mechanical-design/pvc connectors/4wayteejoint.stl
42.0 x 31.0 x 32.0

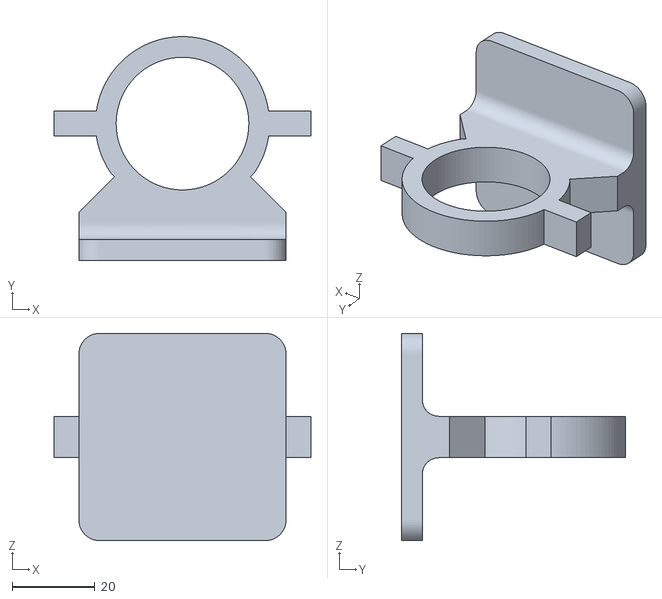
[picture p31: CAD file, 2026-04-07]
mechanical-design/thruster holder/thruster connector.stl
62.0 x 54.0 x 50.0

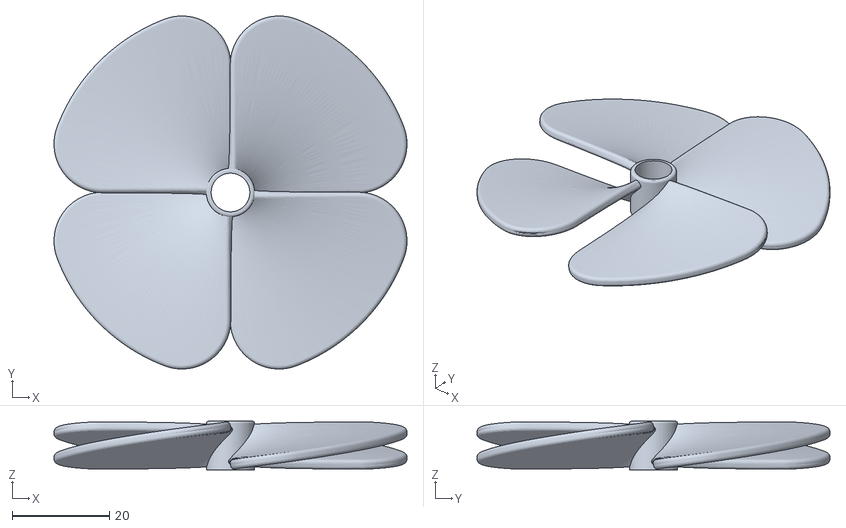
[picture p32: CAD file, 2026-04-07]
mechanical-design/propeller/Propeller_.stl
72.5 x 72.5 x 10.0

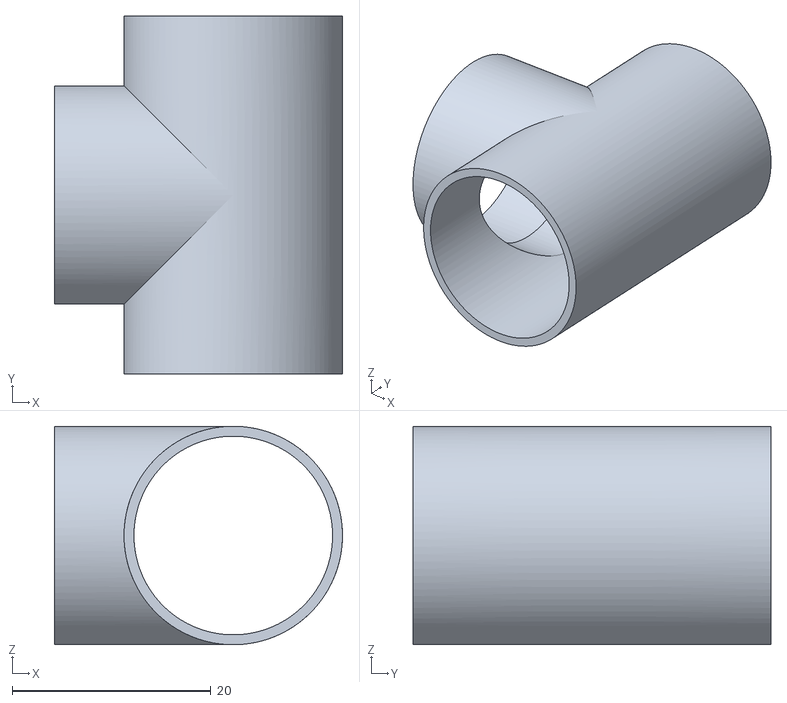
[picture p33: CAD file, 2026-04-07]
mechanical-design/pvc connectors/Tjoint.stl
29.0 x 36.0 x 22.0

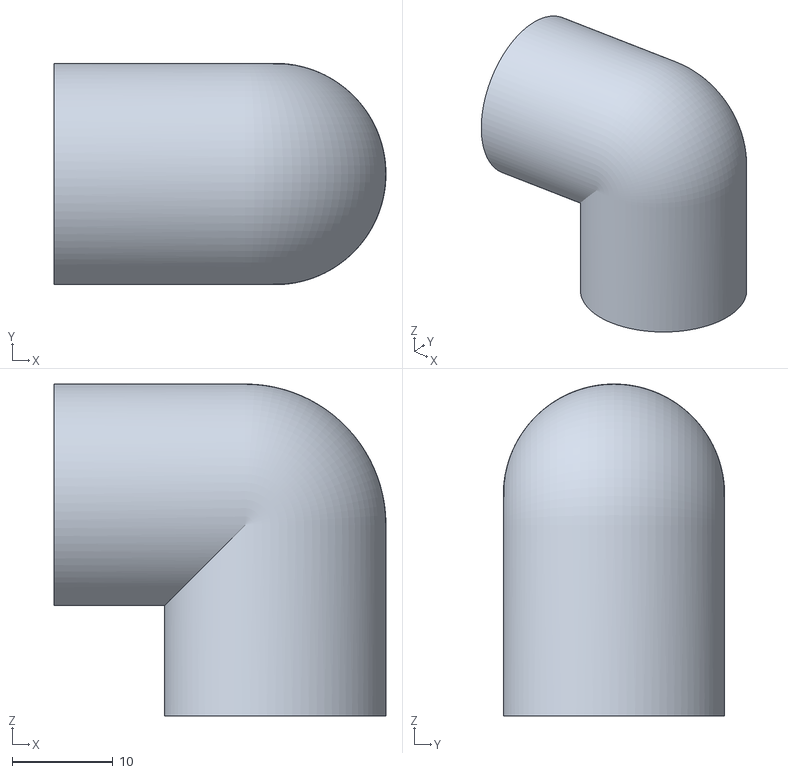
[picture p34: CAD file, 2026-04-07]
mechanical-design/pvc connectors/elbow.stl
33.0 x 22.0 x 33.0

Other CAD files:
system-design/AUV_body_final.stl
